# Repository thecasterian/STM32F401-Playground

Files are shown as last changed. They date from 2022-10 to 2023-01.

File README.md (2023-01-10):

STM32F401 Playground
====================

STM32F401 Breakout Board
------------------------

This is a breakout board for the STM32F401RCT6 microcontroller. It has a built-in ST-Link programmer just like ST's discovery boards. It also has a reset button, 8-MHz HSE crystal, and jumper pins for the BOOT0 and the virtual COM port.

References
----------

* [STM32F401 Reference Manual](https://www.st.com/resource/en/reference_manual/dm00096844-stm32f401xb-c-and-stm32f401xd-e-advanced-arm-based-32-bit-mcus-stmicroelectronics.pdf)
* [Custom ST-Link V2.0 / V2.1 / V3.0](https://hackaday.io/project/179054-custom-st-link-v20-v21-v30)
  * Reference for the hardware and the firmware of ST-Link programmer.

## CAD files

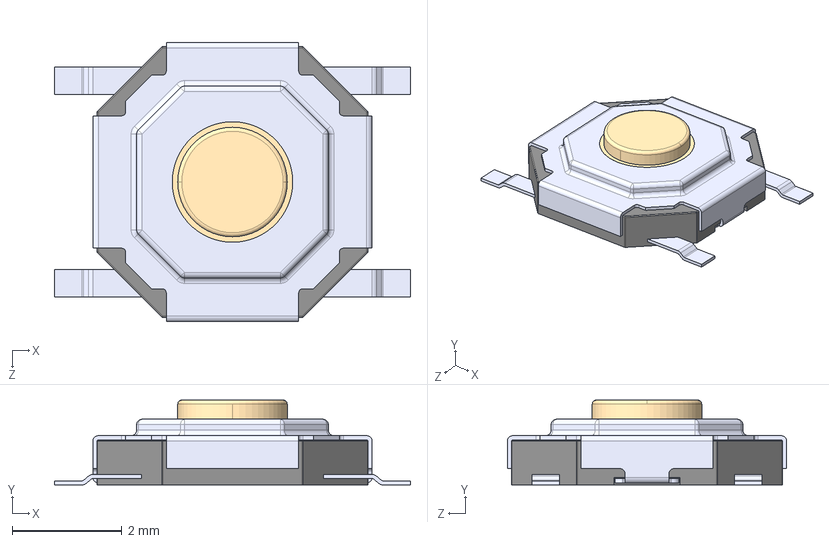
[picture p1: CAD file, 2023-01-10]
Hardware/Custom Parts/TS-1187A-B-A-B.step
6.50 x 1.55 x 5.10 mm

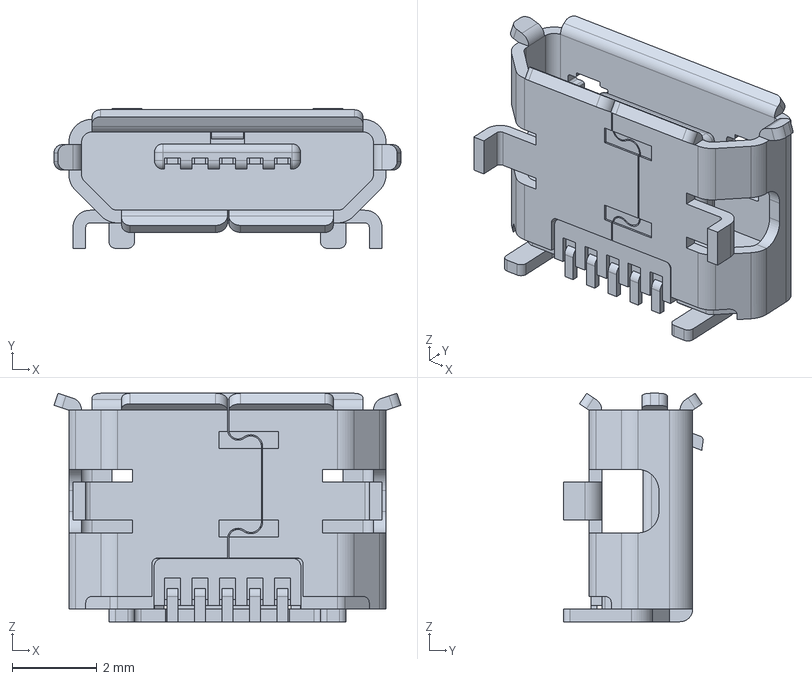
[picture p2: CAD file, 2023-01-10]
Hardware/Custom Parts/1050170001.stp
8.20 x 3.30 x 5.40 mm

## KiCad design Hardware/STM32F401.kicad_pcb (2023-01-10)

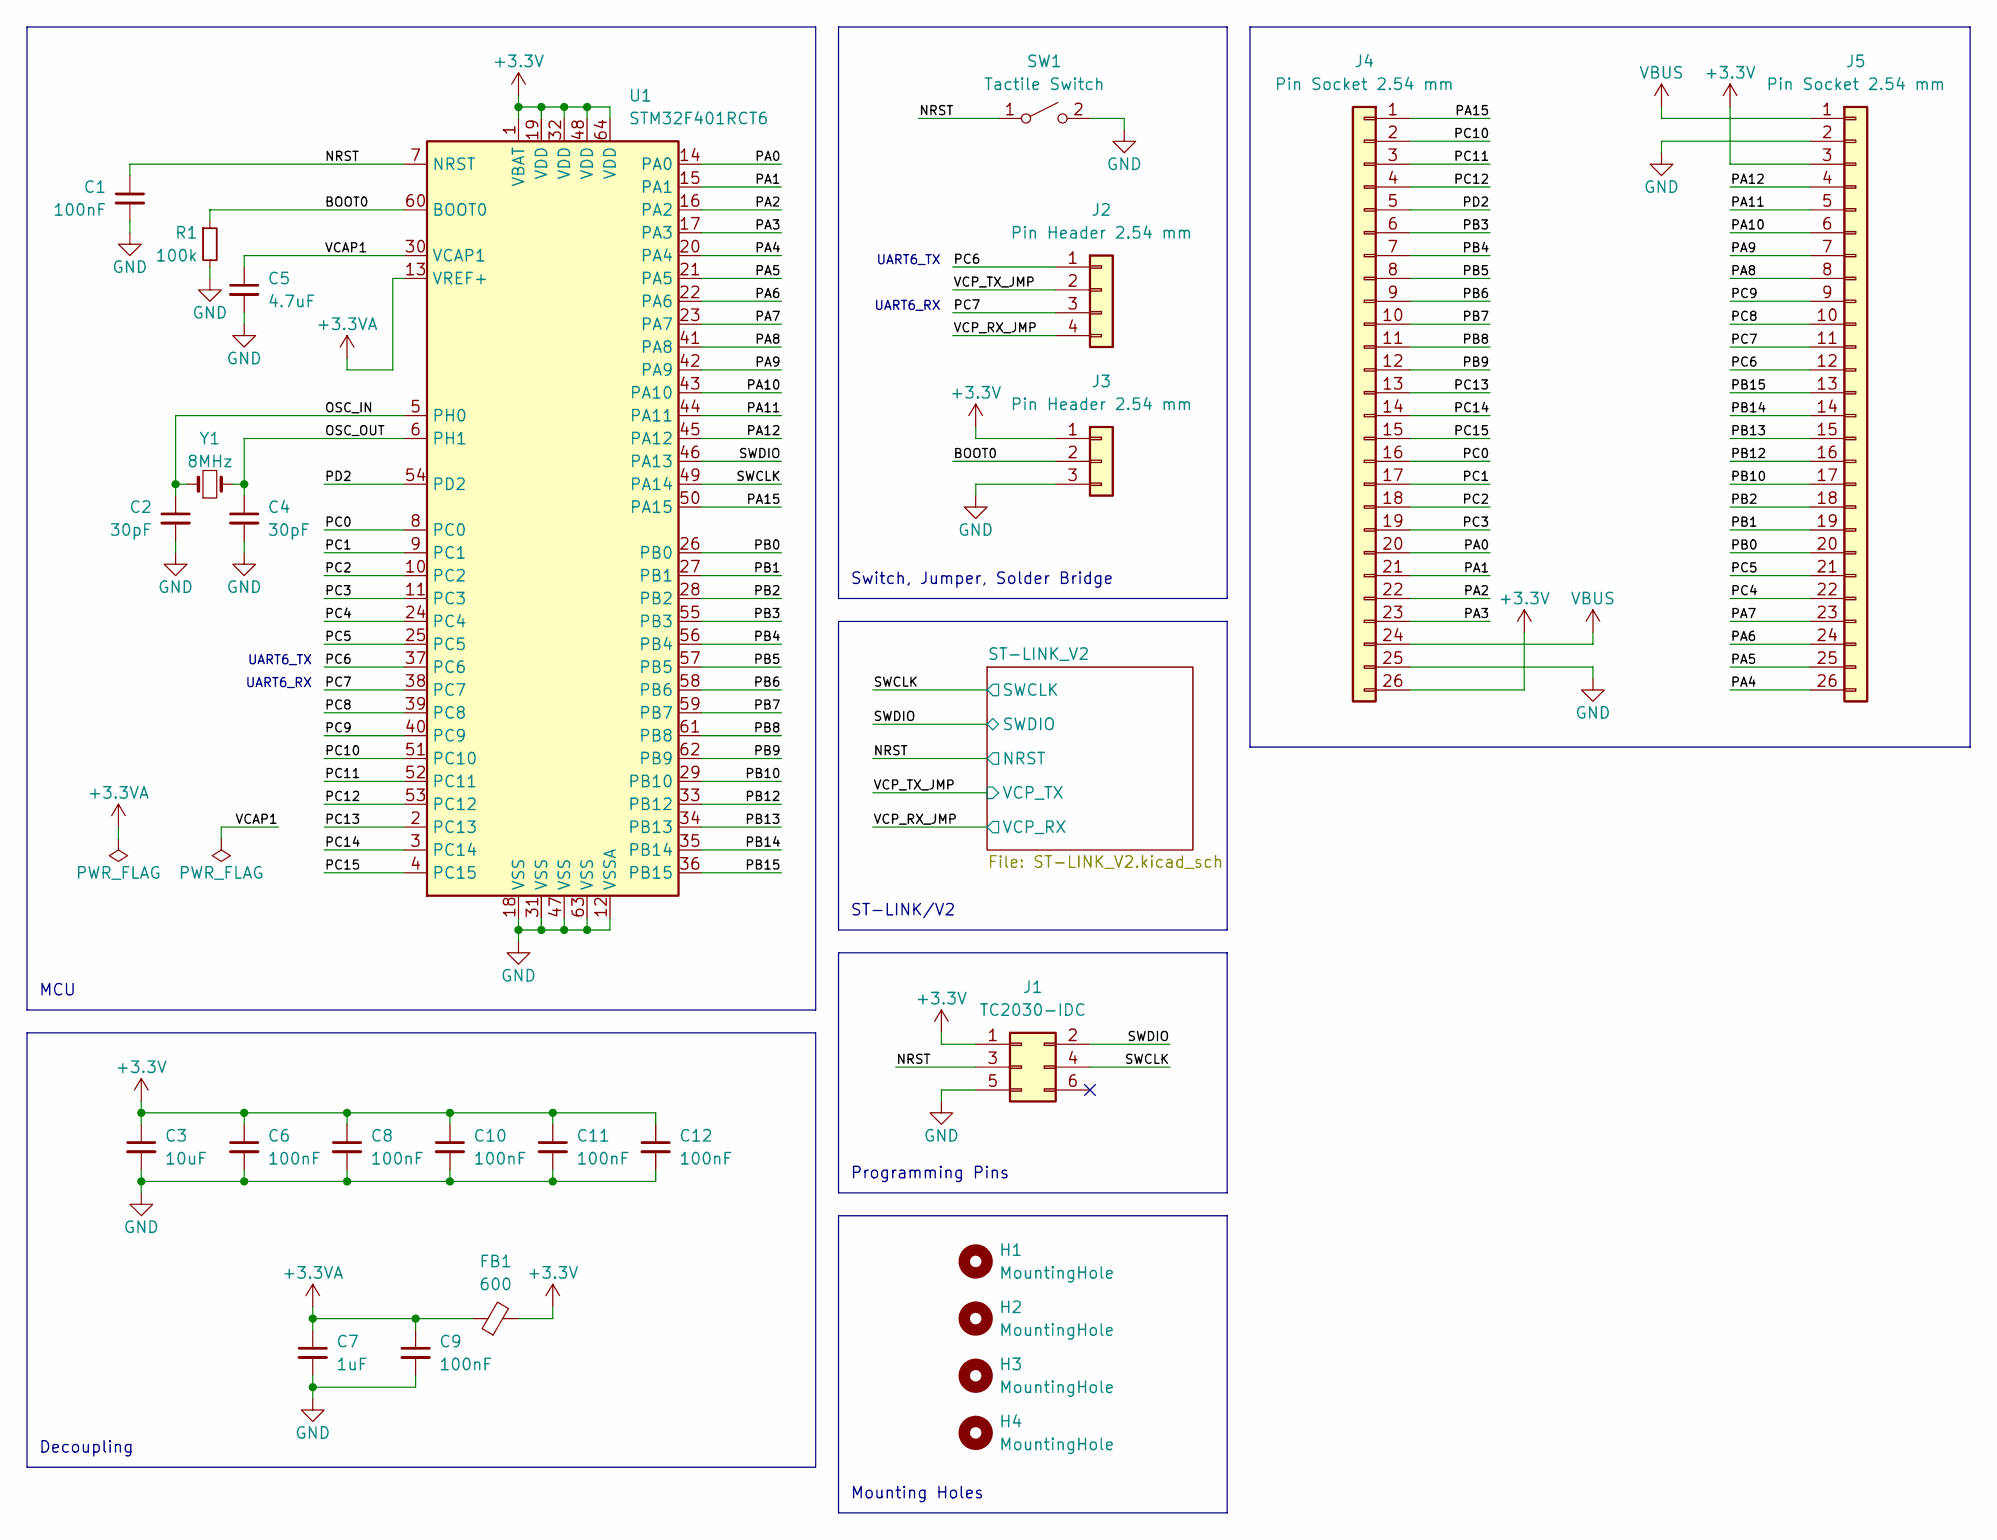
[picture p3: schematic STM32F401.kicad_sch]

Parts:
C1, C6, C8, C9, C10, C11, C12: 100nF; C_0603_1608Metric; LCSC C1525
C2, C4: 30pF; C_0603_1608Metric; LCSC C1570
C3: 10uF; C_0603_1608Metric; LCSC C19702
C5: 4.7uF; C_0603_1608Metric; LCSC C19666
C7: 1uF; C_0603_1608Metric; LCSC C15849
FB1: 600; L_0603_1608Metric; LCSC C1002
H1, H2, H3, H4: MountingHole; MountingHole_2.2mm_M2
J1: TC2030-IDC; Tag-Connect_TC2030-IDC-NL_2x03_P1.27mm_Vertical
J2: Pin Header 2.54 mm; PinHeader_1x04_P2.54mm_Vertical
J3: Pin Header 2.54 mm; PinHeader_1x03_P2.54mm_Vertical
J4, J5: Pin Socket 2.54 mm; PinSocket_1x26_P2.54mm_Vertical
R1: 100k; R_0603_1608Metric; LCSC C25741
SW1: Tactile Switch; SW_TS-1187A-B-A-B; LCSC C318884
U1: STM32F401RCT6; LQFP-64_10x10mm_P0.5mm; LCSC C74524
Y1: 8MHz; Crystal_SMD_5032-2Pin_5.0x3.2mm; LCSC C115962

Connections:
+3.3V: C3.1, C6.1, C8.1, C10.1, C11.1, C12.1, FB1.2, J1.1, J3.1, J4.26, J5.3, U1.1 (VBAT), U1.19 (VDD), U1.32 (VDD), U1.48 (VDD), U1.64 (VDD); also elsewhere on the board
+3.3VA: C7.1, C9.1, FB1.1, U1.13 (VREF+)
/BOOT0: J3.2, R1.1, U1.60 (BOOT0)
/NRST: C1.1, J1.3, SW1.1 (A), U1.7 (NRST); also elsewhere on the board
/OSC_IN: C2.1, U1.5 (PH0), Y1.1
/OSC_OUT: C4.1, U1.6 (PH1), Y1.2
/PA0: J4.20, U1.14 (PA0)
/PA1: J4.21, U1.15 (PA1)
/PA2: J4.22, U1.16 (PA2)
/PA3: J4.23, U1.17 (PA3)
/PA4: J5.26, U1.20 (PA4)
/PA5: J5.25, U1.21 (PA5)
/PA6: J5.24, U1.22 (PA6)
/PA7: J5.23, U1.23 (PA7)
/PA8: J5.8, U1.41 (PA8)
/PA9: J5.7, U1.42 (PA9)
/PA10: J5.6, U1.43 (PA10)
/PA11: J5.5, U1.44 (PA11)
/PA12: J5.4, U1.45 (PA12)
/PA15: J4.1, U1.50 (PA15)
/PB0: J5.20, U1.26 (PB0)
/PB1: J5.19, U1.27 (PB1)
/PB2: J5.18, U1.28 (PB2)
/PB3: J4.6, U1.55 (PB3)
/PB4: J4.7, U1.56 (PB4)
/PB5: J4.8, U1.57 (PB5)
/PB6: J4.9, U1.58 (PB6)
/PB7: J4.10, U1.59 (PB7)
/PB8: J4.11, U1.61 (PB8)
/PB9: J4.12, U1.62 (PB9)
/PB10: J5.17, U1.29 (PB10)
/PB12: J5.16, U1.33 (PB12)
/PB13: J5.15, U1.34 (PB13)
/PB14: J5.14, U1.35 (PB14)
/PB15: J5.13, U1.36 (PB15)
/PC0: J4.16, U1.8 (PC0)
/PC1: J4.17, U1.9 (PC1)
/PC2: J4.18, U1.10 (PC2)
/PC3: J4.19, U1.11 (PC3)
/PC4: J5.22, U1.24 (PC4)
/PC5: J5.21, U1.25 (PC5)
/PC6: J2.1, J5.12, U1.37 (PC6)
/PC7: J2.3, J5.11, U1.38 (PC7)
/PC8: J5.10, U1.39 (PC8)
/PC9: J5.9, U1.40 (PC9)
/PC10: J4.2, U1.51 (PC10)
/PC11: J4.3, U1.52 (PC11)
/PC12: J4.4, U1.53 (PC12)
/PC13: J4.13, U1.2 (PC13)
/PC14: J4.14, U1.3 (PC14)
/PC15: J4.15, U1.4 (PC15)
/PD2: J4.5, U1.54 (PD2)
/SWCLK: J1.4, U1.49 (PA14); also elsewhere on the board
/SWDIO: J1.2, U1.46 (PA13); also elsewhere on the board
/VCAP1: C5.1, U1.30 (VCAP1)
/VCP_RX_JMP: J2.4; also elsewhere on the board
/VCP_TX_JMP: J2.2; also elsewhere on the board
GND: C1.2, C2.2, C3.2, C4.2, C5.2, C6.2, C7.2, C8.2, C9.2, C10.2, C11.2, C12.2, J1.5, J3.3, J4.25, J5.2, R1.2, SW1.2 (B), U1.12 (VSSA), U1.18 (VSS), U1.31 (VSS), U1.47 (VSS), U1.63 (VSS); also elsewhere on the board
VBUS: J4.24, J5.1; also elsewhere on the board

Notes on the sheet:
Switch, Jumper, Solder Bridge
MCU
UART6_TX
Programming Pins
UART6_RX
ST-LINK/V2
Decoupling
Mounting Holes

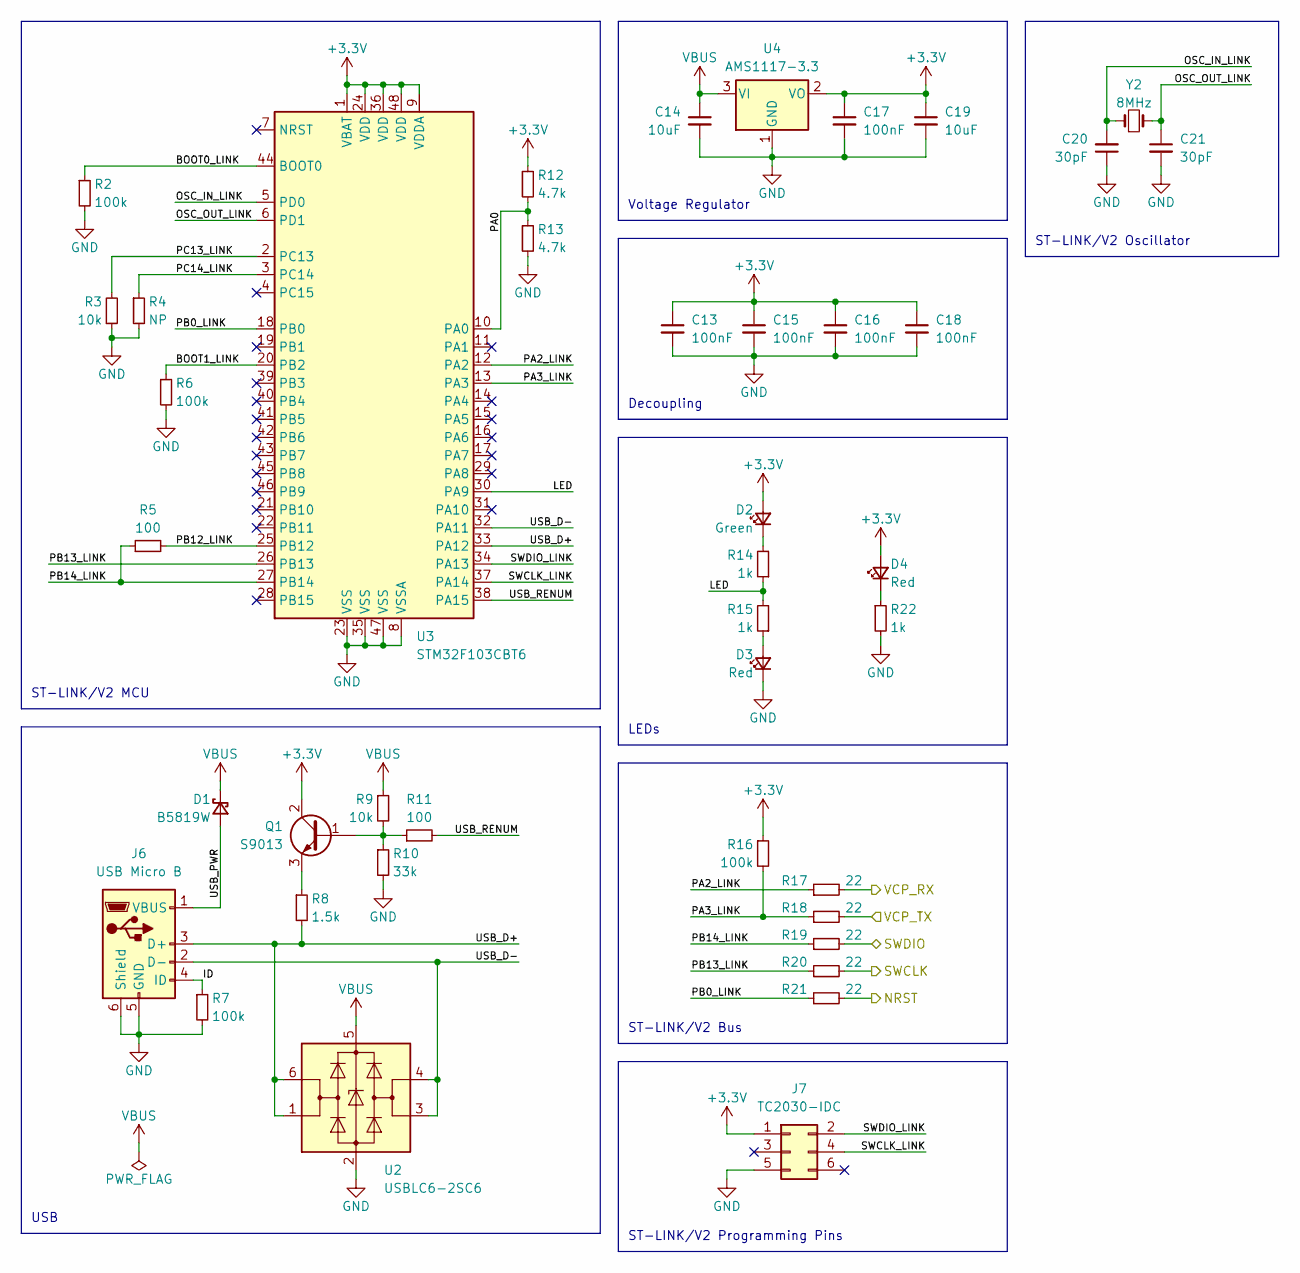
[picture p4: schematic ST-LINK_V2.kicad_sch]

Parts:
C13, C15, C16, C17, C18: 100nF; C_0603_1608Metric
C14, C19: 10uF; C_0603_1608Metric
C20, C21: 30pF; C_0603_1608Metric
D1: B5819W; D_SOD-123; LCSC C8598
D2: Green; LED_0603_1608Metric; LCSC C72043
D3, D4: Red; LED_0603_1608Metric; LCSC C2286
J6: USB Micro B; USB_Micro-B_Molex-105017-0001; LCSC C136000
J7: TC2030-IDC; Tag-Connect_TC2030-IDC-NL_2x03_P1.27mm_Vertical
Q1: S9013; SOT-23; LCSC C6749
R2, R6, R7, R16: 100k; R_0603_1608Metric
R3, R9: 10k; R_0603_1608Metric
R4: NP; R_0603_1608Metric
R5, R11: 100; R_0603_1608Metric
R8: 1.5k; R_0603_1608Metric
R10: 33k; R_0603_1608Metric
R12, R13: 4.7k; R_0603_1608Metric
R14, R15, R22: 1k; R_0603_1608Metric
R17, R18, R19, R20, R21: 22; R_0603_1608Metric
U2: USBLC6-2SC6; SOT-23-6
U3: STM32F103CBT6; LQFP-48_7x7mm_P0.5mm; LCSC C8304
U4: AMS1117-3.3; SOT-223-3_TabPin2; LCSC C6186
Y2: 8MHz; Crystal_SMD_5032-2Pin_5.0x3.2mm; LCSC C115962

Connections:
+3.3V: C13.1, C15.1, C16.1, C17.1, C18.1, C19.1, D2.2 (A), D4.2 (A), J7.1, Q1.2 (C), R12.1, R16.1, U3.1 (VBAT), U3.9 (VDDA), U3.24 (VDD), U3.36 (VDD), U3.48 (VDD), U4.2 (VO); also elsewhere on the board
/NRST: R21.2; also elsewhere on the board
/ST-LINK_V2/BOOT0_LINK: R2.1, U3.44 (BOOT0)
/ST-LINK_V2/BOOT1_LINK: R6.1, U3.20 (PB2)
/ST-LINK_V2/ID: J6.4 (ID), R7.1
/ST-LINK_V2/LED: R14.1, R15.2, U3.30 (PA9)
/ST-LINK_V2/OSC_IN_LINK: C20.2, U3.5 (PD0), Y2.1
/ST-LINK_V2/OSC_OUT_LINK: C21.1, U3.6 (PD1), Y2.2
/ST-LINK_V2/PA0: R12.2, R13.1, U3.10 (PA0)
/ST-LINK_V2/PA2_LINK: R17.1, U3.12 (PA2)
/ST-LINK_V2/PA3_LINK: R16.2, R18.1, U3.13 (PA3)
/ST-LINK_V2/PB0_LINK: R21.1, U3.18 (PB0)
/ST-LINK_V2/PB12_LINK: R5.2, U3.25 (PB12)
/ST-LINK_V2/PB13_LINK: R20.1, U3.26 (PB13)
/ST-LINK_V2/PB14_LINK: R5.1, R19.1, U3.27 (PB14)
/ST-LINK_V2/PC13_LINK: R3.2, U3.2 (PC13)
/ST-LINK_V2/PC14_LINK: R4.1, U3.3 (PC14)
/ST-LINK_V2/SWCLK_LINK: J7.4, U3.37 (PA14)
/ST-LINK_V2/SWDIO_LINK: J7.2, U3.34 (PA13)
/ST-LINK_V2/USB_D+: J6.3 (D+), R8.2, U2.1 (I/O1), U2.6 (I/O1), U3.33 (PA12)
/ST-LINK_V2/USB_D-: J6.2 (D-), U2.3 (I/O2), U2.4 (I/O2), U3.32 (PA11)
/ST-LINK_V2/USB_PWR: D1.2 (A), J6.1 (VBUS)
/ST-LINK_V2/USB_RENUM: R11.2, U3.38 (PA15)
/SWCLK: R20.2; also elsewhere on the board
/SWDIO: R19.2; also elsewhere on the board
/VCP_RX_JMP: R17.2; also elsewhere on the board
/VCP_TX_JMP: R18.2; also elsewhere on the board
GND: C13.2, C14.2, C15.2, C16.2, C17.2, C18.2, C19.2, C20.1, C21.2, D3.1 (K), J6.5 (GND), J6.6 (Shield), J7.5, R2.2, R3.1, R4.2, R6.2, R7.2, R10.2, R13.2, R22.2, U2.2 (GND), U3.8 (VSSA), U3.23 (VSS), U3.35 (VSS), U3.47 (VSS), U4.1 (GND); also elsewhere on the board
unnamed: D2.1 (K), R14.2
unnamed: D3.2 (A), R15.1
unnamed: D4.1 (K), R22.1
unnamed: Q1.1 (B), R9.2, R10.1, R11.1
unnamed: Q1.3 (E), R8.1
VBUS: C14.1, D1.1 (K), R9.1, U2.5 (VBUS), U4.3 (VI); also elsewhere on the board

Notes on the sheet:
Voltage Regulator
ST-LINK/V2 Programming Pins
USB
ST-LINK/V2 MCU
ST-LINK/V2 Bus
LEDs
Decoupling
ST-LINK/V2 Oscillator

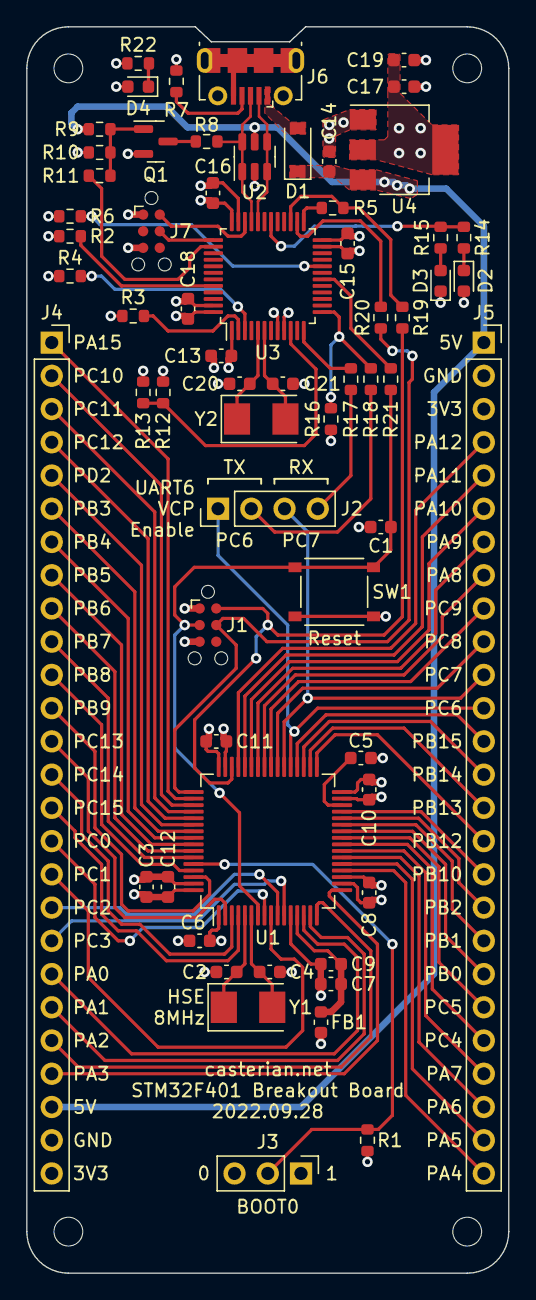
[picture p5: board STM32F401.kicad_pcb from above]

Board: 4 copper layers, 36.8 x 95.2 mm, 67 parts (0 on the bottom side), 85 nets.

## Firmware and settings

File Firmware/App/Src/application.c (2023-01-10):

#include <stdio.h>
#include <string.h>
#include "ahrs.h"
#include "application.h"
#include "math.h"
#include "timer_wrapper.h"
#include "quaternion.h"
#include "usart.h"

#define PERIOD 0.002f

static mpu9250_t mpu9250;
static ahrs_t ahrs;

int _write(int file, char *ptr, int len);

static ahrs_status_t read_acc(void *aux, float *data);
static ahrs_status_t read_gyro(void *aux, float *data);
static ahrs_status_t read_mag(void *aux, float *data);

void setup(void) {
    timer_start();

    mpu9250_init(&mpu9250, &hspi2, MPU9250_NSS_GPIO_Port, MPU9250_NSS_Pin);
    ahrs_init(&ahrs, PERIOD, read_acc, &mpu9250, read_gyro, &mpu9250, read_mag, &mpu9250);

    ahrs_init_attitude(&ahrs, 1000U);
}

void loop(void) {
    float roll, pitch, yaw;
    uint8_t buf[13];

    if (timer.period_elapsed) {
        ahrs_update(&ahrs);

        quaternion_to_euler(&ahrs.q, &roll, &pitch, &yaw);
        buf[0] = 0x42;
        memcpy(&buf[1], &roll, sizeof(roll));
        memcpy(&buf[5], &pitch, sizeof(pitch));
        memcpy(&buf[9], &yaw, sizeof(yaw));
        _write(0, (char *)buf, sizeof(buf));

        timer.period_elapsed = false;
    }
}

int _write(int file, char *ptr, int len) {
    UNUSED(file);

    if (HAL_UART_Transmit(&huart6, (uint8_t *)ptr, len, HAL_MAX_DELAY) != HAL_OK)
        return -1;

    return len;
}

static ahrs_status_t read_acc(void *aux, float *data) {
    return mpu9250_read_acc(aux, data) == MPU9250_OK ? AHRS_OK : AHRS_ERR;
}

static ahrs_status_t read_gyro(void *aux, float *data) {
    return mpu9250_read_gyro(aux, data) == MPU9250_OK ? AHRS_OK : AHRS_ERR;
}

static ahrs_status_t read_mag(void *aux, float *data) {
    return mpu9250_read_mag(aux, data) == MPU9250_OK ? AHRS_OK : AHRS_ERR;
}

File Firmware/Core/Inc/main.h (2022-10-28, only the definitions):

#define MPU9250_NSS_Pin GPIO_PIN_1
#define MPU9250_NSS_GPIO_Port GPIOC
#define W25Q128JV_NSS_Pin GPIO_PIN_4
#define W25Q128JV_NSS_GPIO_Port GPIOA

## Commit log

2022-10-23 Implement W25Q128JV flash driver
2022-10-28 Implement MPU9250 accelerometer and gyro interface
2022-11-04 Implement AHRS with only gyro
2022-11-05 Add accelerometer to AHRS
2022-11-05 Implement magnetometer interface
2022-11-07 Add magnetometer to AHRS
2022-11-13 Fix bug on quaternion calculation
    [application.c]
2023-01-10 Add hardware
    [1050170001.stp, ST-LINK_V2.kicad_sch, STM32F401.kicad_pcb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]

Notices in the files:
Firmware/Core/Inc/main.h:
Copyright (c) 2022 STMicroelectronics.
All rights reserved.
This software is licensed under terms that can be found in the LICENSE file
